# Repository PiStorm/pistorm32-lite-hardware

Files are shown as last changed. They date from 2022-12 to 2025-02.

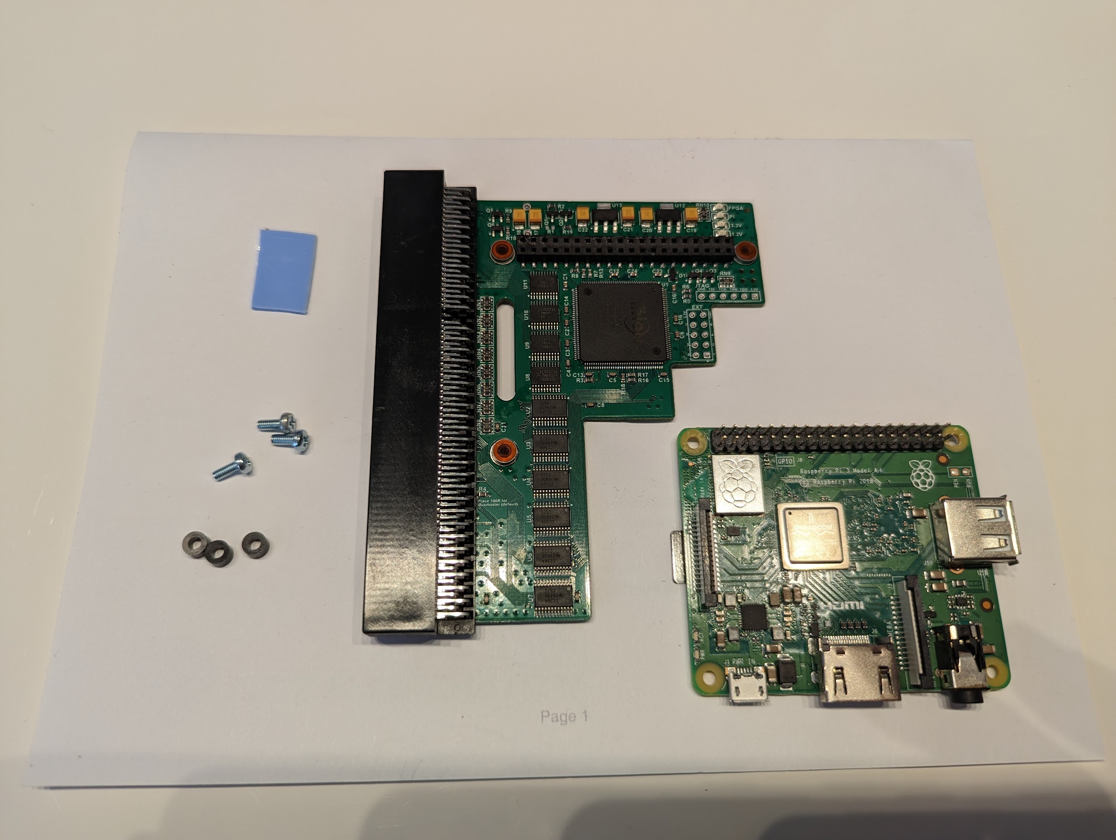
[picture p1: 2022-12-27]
Pictures/parts.jpg

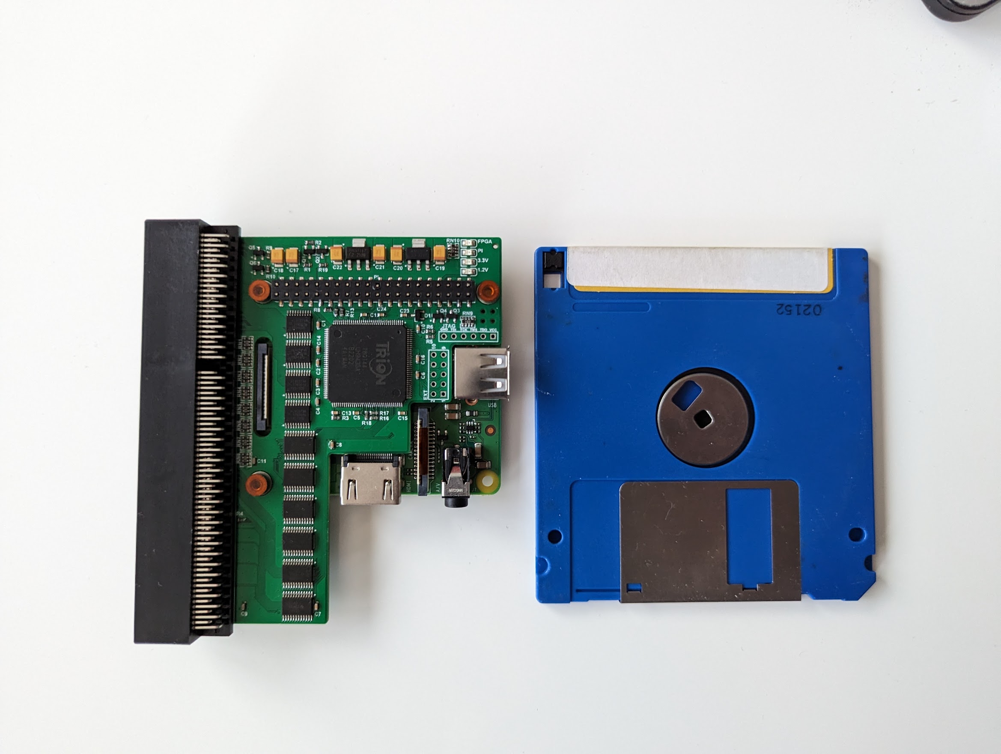
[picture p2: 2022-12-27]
Pictures/PS32_lite_pi3A.jpg

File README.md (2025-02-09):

# PiStorm32-lite
## An Opensource, Raspberry Pi based, Amiga A1200 Accelerator

This repository holds all hardware design and fabrication files

---

PiStorm32-lite is compatible with 
- PI3A
- PI3B
- PI4B
- PiZero2 (could be very tight around the HDMI connector...)

- Raspberry CM4 (Recommended Version : CM4 Lite, 2GB RAM with WIFI and no eMMC) trough a adapter
  https://github.com/PiStorm/cm4board
  
The custom designed CM4 Adapter will offer the best cooling and electrical properties in the constrained space available.



## Direct links
- [Schematics (and assembly drawing)](PDF/ps32_lite_rev_a_public_schematic.pdf)
- [Altium project](Altium/)
- [Fabrication files](Fabrication%20Files/)
- [Fabrication files for JLCPCB Assembly (With small ordering Howto)](JLCPCB/)

---

The community around the PiStorm Project is best reached on Discord



---
> IMPORTANT NOTE: `Isolate the PI GPIO and Ethernet Pins from the A1200 Keyboard, that can be done by 2  or 3 layers of tape attached to the keyboard backside where the Pi pins would touch the metal`
If you don't do that, you likely fry your Pi ! Sorry couldn't design it an other way, there is not much space in the A1200 trapdoor bay 
---

Beside the PCB you also need following parts:

| Designator  | Part | Quantity | Notes
| --- | --- | ----- | ----- |
| C1 to C16, C23, C24 | 100nF 0603 | 18 | X7R 
| C17, C18, C19, C20, C21, C22 | Tantalum 10uF 16V Size B| 6 | --
| D1 | BAT54C | 1 | --
| EXT | 2.54mm Pin Header 2x5 10 Pins | 1 | Expansion header for the future :) e.g.  B-2100S10P-B110
| M1,M2,M3 | SMD M2.5 NUT | 3 | e.g. Sinhoo SMTSO2515CTJ
| LED_1.2, LED_3.3, LED_FPGA, LED_PI | RED LED 0805 | 4 | Indicate not Illuminate!
| PI | SMD 40Pin 2x20 - bottom entry | 1 | e.g. Liansheng FH-00369 
| CN1 | A1200 Edge connector | 1 | see links and notes
| Q1 | IRML6401 | 1 | --
| Q2, Q3, Q4, Q5, Q6 | BC847B | 5 | --
| R2, R4, R5, R6, R7, R8, R9, R10, R19 | Resistor 0603 10kOhm | 9 | --
| R3, R13, R16, R17, R18 | Resistor 0603 1kOhm | 5 | --
| RN1, RN2, RN3, RN4, RN5, RN6, RN7, RN8, RN9| Resistor Array 0603x4 10kOhm | 9 | e.g. YAGEO YC164-JR
| RN10 | Resistor Array 0603x4 1kOhm | 1 | e.g. YAGEO YC164-JR
| U1 | FPGA Efinix Trion T8Q144C4 (or C3) | 1 | see links and notes
| U2, U3, U4, U5, U6, U7 | 74CBTD3384 TSSOP-24 | 6 | TI or NXP
| U8, U9, U10, U11 | 74LVC573A TSSOP-20 | 4 | TI or NXP
| U12 | AMS1117-3.3 3.3V LDO | 1 | --
| U13 | AMS1117-3 1.2 1.2V LDO | 1 | --

> Note: A1200 Edge Connectors can be purchased at [retroready.one](https://retroready.one/products/amiga-1200-genuine-expansion-card-edge-connector-brand-new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)(UK based, highly recommended) or [amigastore.eu](https://amigastore.eu/en/738-amiga-1200-accelerator-connector-for-the-edge-expansion-port.html)(EU based) or [Sordan](https://sordan.ie/product/670/150-pin-90-degrees-amiga-1200-edge-expansion-card-connector/)(Ireland/EU based)

> Note: JLCPCB does not stock the Efinix FPGA, but can source that part trough their [global parts sourcing service](https://jlcpcb.com/help/article/60-How-to-use-JLCPCB-Global-Sourcing-Parts-Service). If you want to assemble the PCB by yourself, or order a partially assembeld PCB without the FPGA then here is a link to Digikey [Digikey FPGA](https://www.digikey.com/short/zh3ph422)

For mechanical assembly you need :

- 3 M2.5 Screws with 8mm thread length (M2.5x8)
- 3 Spacers ID=2.6mm Length=3.0mm 
- 1 Thermal Pad with 1mm thickness, just needs to be big enough to cover the PI CPU 

There are also some [pictures here](Pictures/) how to attach the thermal pad and screws

---

If you like this project and want to support me (Claude Schwarz, PiStorm Hardware) with a donation, I finally setup a donate button :)

The donations will go into further development of open source PiStorm hardware.



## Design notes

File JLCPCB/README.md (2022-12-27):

# PiStorm32-lite
## How to place the order at JLCPCB

- Logic or create a account at [JLCPCB](https://jlcpcb.com/)
- Click on `Instant Quote`
- Upload the ZIP File with the Gerbers

----

First the PCB, if you only want a unpopulated PCB you can of course skip the Assembly part :)

----

## PCB

Check if the Gerber upload looks good


Check the PCB specs (you can also pick a different color or PCB finish of course)


Check that "Remove Order Number" is set like this


----

## Assembly

Select "Top Side" for Assembly and set the tooling holes to "Added by Customer"


Continue to the next Page to upload the BOM (Bill of Material) and CPL (Pick and Place Machine coordinates) files.
You also need to specify the intended use for the assembled PCB, thats for Tax/Customs reasons only. I usually pick
the Research/DIY/Hobby category.



On the next Page you can check the BOM upload and matching to JLCPCB part numbers and stock levels.
For all parts you can also select alternatives from JLCPCBs stock (Loupe symbol), or like in the case of the EFINIX FPGA which
isn't yet on the JLCPCBs stock list, select a part you ordred before at the JLCPCB Global Parts Sourcing Service.
Keep in mind that the Parts you ordered that way must first arrive at the JLCPCB warehouse before the assembly and data prepareation can start.
This takes usually around a week, and you get a email notification when the parts arrived.



When all looks good and the parts, or alternative parts you selected, are on stock proceed to the last page.
Here you can check the placement of the parts prior soldering. JLCPCB corrects small errors like rotated parts, but 
they cant correct errors where, for example, a part is selected with the wrong footprint. So check the picture closely and
if in doubt better double check :) The rendering is not perfect, like the FPGA is missing completly in the rendering.
But when you are sure the part is on stock and you selected it in the BOM page then just trust in JLCPCB. They contact you
also if there is a problem they cant fix by themself for you.



Thats it! Now lean back and wait some days for your assembled PiStorm32-lite boards to arrive

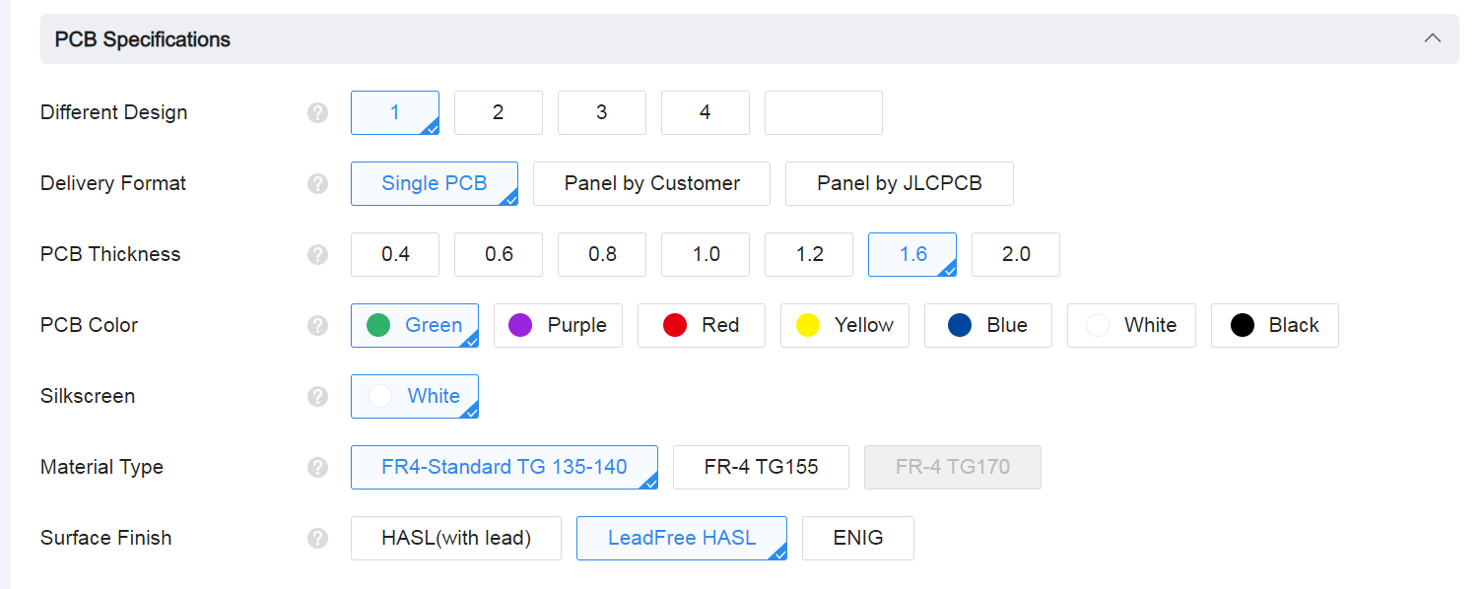
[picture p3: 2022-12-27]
JLCPCB/pictures/pcb_spec.png

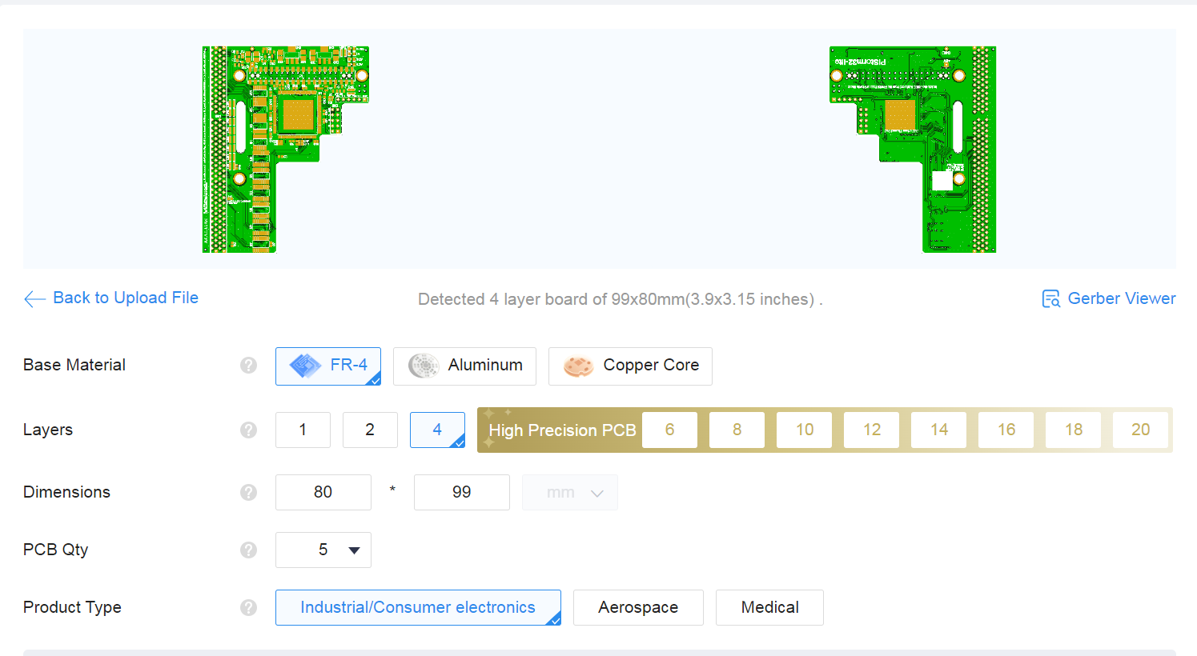
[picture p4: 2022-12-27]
JLCPCB/pictures/gerber upload.png

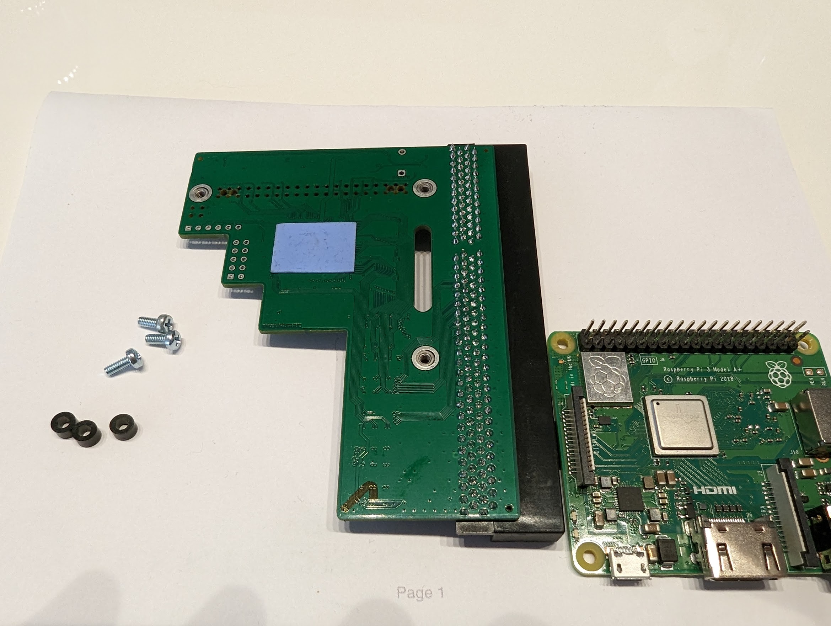
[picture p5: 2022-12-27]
Pictures/thermal_pad.jpg

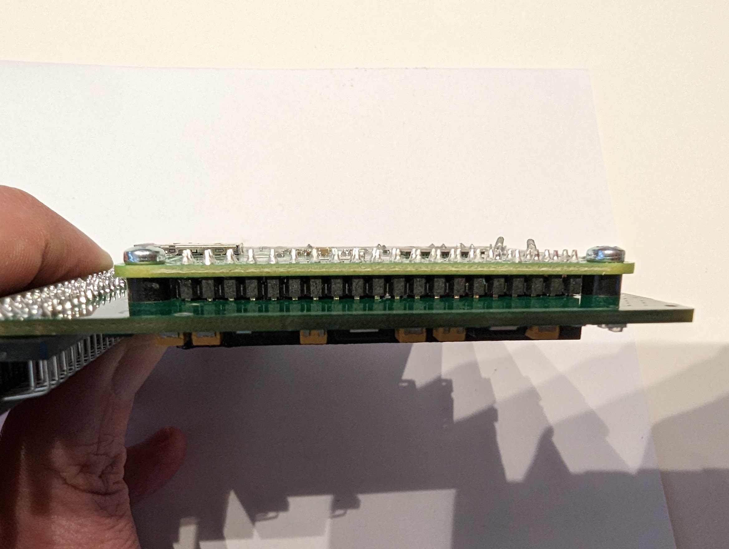
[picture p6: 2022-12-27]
Pictures/spacer.jpg

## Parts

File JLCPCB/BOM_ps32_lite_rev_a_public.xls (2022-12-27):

Comment | Designator | Footprint | JLCPCB Part #
2.2k | RN10 | 2.2k | C136829
10kΩ | RN1,RN2,RN3,RN4,RN5,RN6,RN7,RN8,RN9 | 10kΩ | C29718
TAJA | C17,C18,C19,C20,C21,C22 | TAJA | C7193
IRLML6401 | Q1 | IRLML6401 | C518776
BC847B | Q2,Q3,Q4,Q5,Q6 | BC847B | C181140
T8Q144Cx | U1 | T8Q144Cx | C5246494
BAT54C | D1 | BAT54C | C909965
AMS1117-1.2 | U13 | AMS1117-1.2 | C347218
SN74LVC573APWLE | U8,U9,U10,U11 | SN74LVC573APWLE | C6096
SN74CBTD3384PWLE | U2,U3,U4,U5,U6,U7 | SN74CBTD3384PWLE | C7155
Comment | DESIGNATOR1,DESIGNATOR2,DESIGNATOR3 | Comment | C2915629
FC-2012HRK-620D | LED_1.2,LED_3.3,LED_FPGA,LED_PI | FC-2012HRK-620D | C84256
AMS1117-3.3 | U12 | AMS1117-3.3 | C6186
E0424-846-00 | R2,R4,R5,R6,R7,R8,R9,R10,R19 | E0424-846-00 | C25804
CapSemi | C1,C2,C3,C4,C5,C6,C7,C8,C9,C10,C11,C12,C13,C14,C15,C16,C24,C23 | CapSemi | C14663
1K | R3,R13,R16,R17,R18 | 1K | C21190
Header20X2 | PI | Header20X2 | C2685115

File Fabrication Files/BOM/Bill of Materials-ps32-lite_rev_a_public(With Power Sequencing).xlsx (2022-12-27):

Comment | Designator | Quantity | BOM_Supplier Part
Cap Semi | C1, C2, C3, C4, C5, C6, C7, C8, C9, C10, C11, C12, C13, C14, C15, C16, C23, C24 | 18
TAJA | C17, C18, C19, C20, C21, C22 | 6
A1200-EXPANSION_SLOT | CN1 | 1
BAT54C | D1 | 1
Header 5X2 | EXT | 1
FC-2012HRK-620D | LED_1.2, LED_3.3, LED_FPGA, LED_PI | 4 | C84256
Mount | M1, M2, M3 | 3
Header 20X2 | PI | 1
IRLML6401 | Q1 | 1
BC847B | Q2, Q3, Q4, Q5, Q6 | 5
E0424-846-00 | R2, R4, R5, R6, R7, R8, R9, R10, R19 | 9
E0424-846-00 | R3, R13 | 2
1K | R16, R17, R18 | 3
10kΩ | RN1, RN2, RN3, RN4, RN5, RN6, RN7, RN8, RN9 | 9 | C29718
2.2k | RN10 | 1 | C29718
T8Q144Cx | U1 | 1
SN74CBTD3384PWLE | U2, U3, U4, U5, U6, U7 | 6
SN74LVC573APWLE | U8, U9, U10, U11 | 4
AMS1117-3.3 | U12 | 1
AMS1117-1.2 | U13 | 1

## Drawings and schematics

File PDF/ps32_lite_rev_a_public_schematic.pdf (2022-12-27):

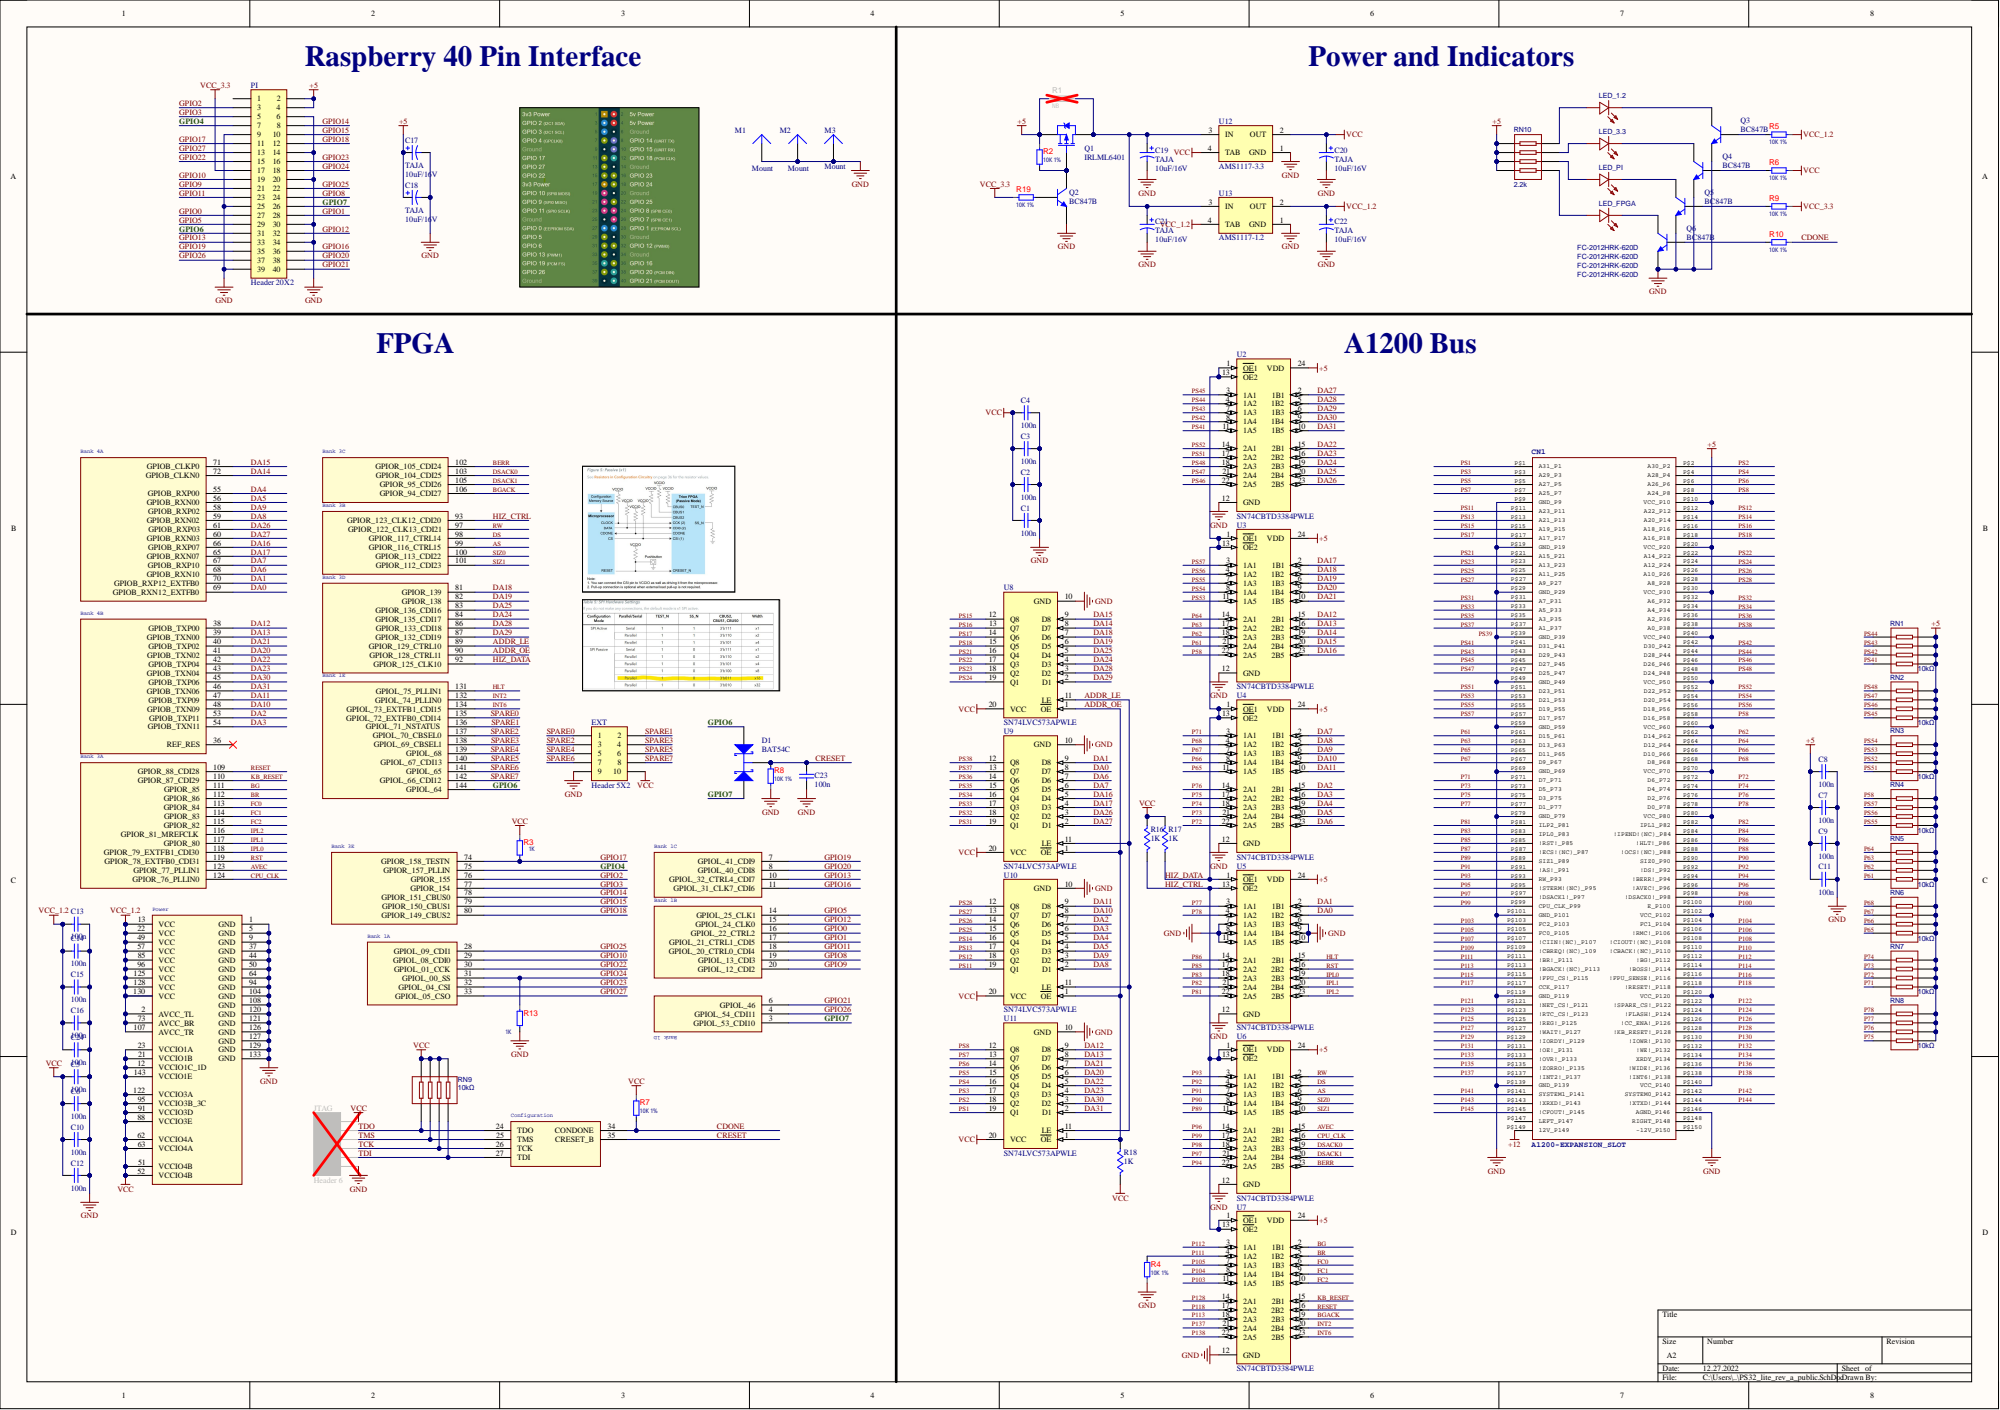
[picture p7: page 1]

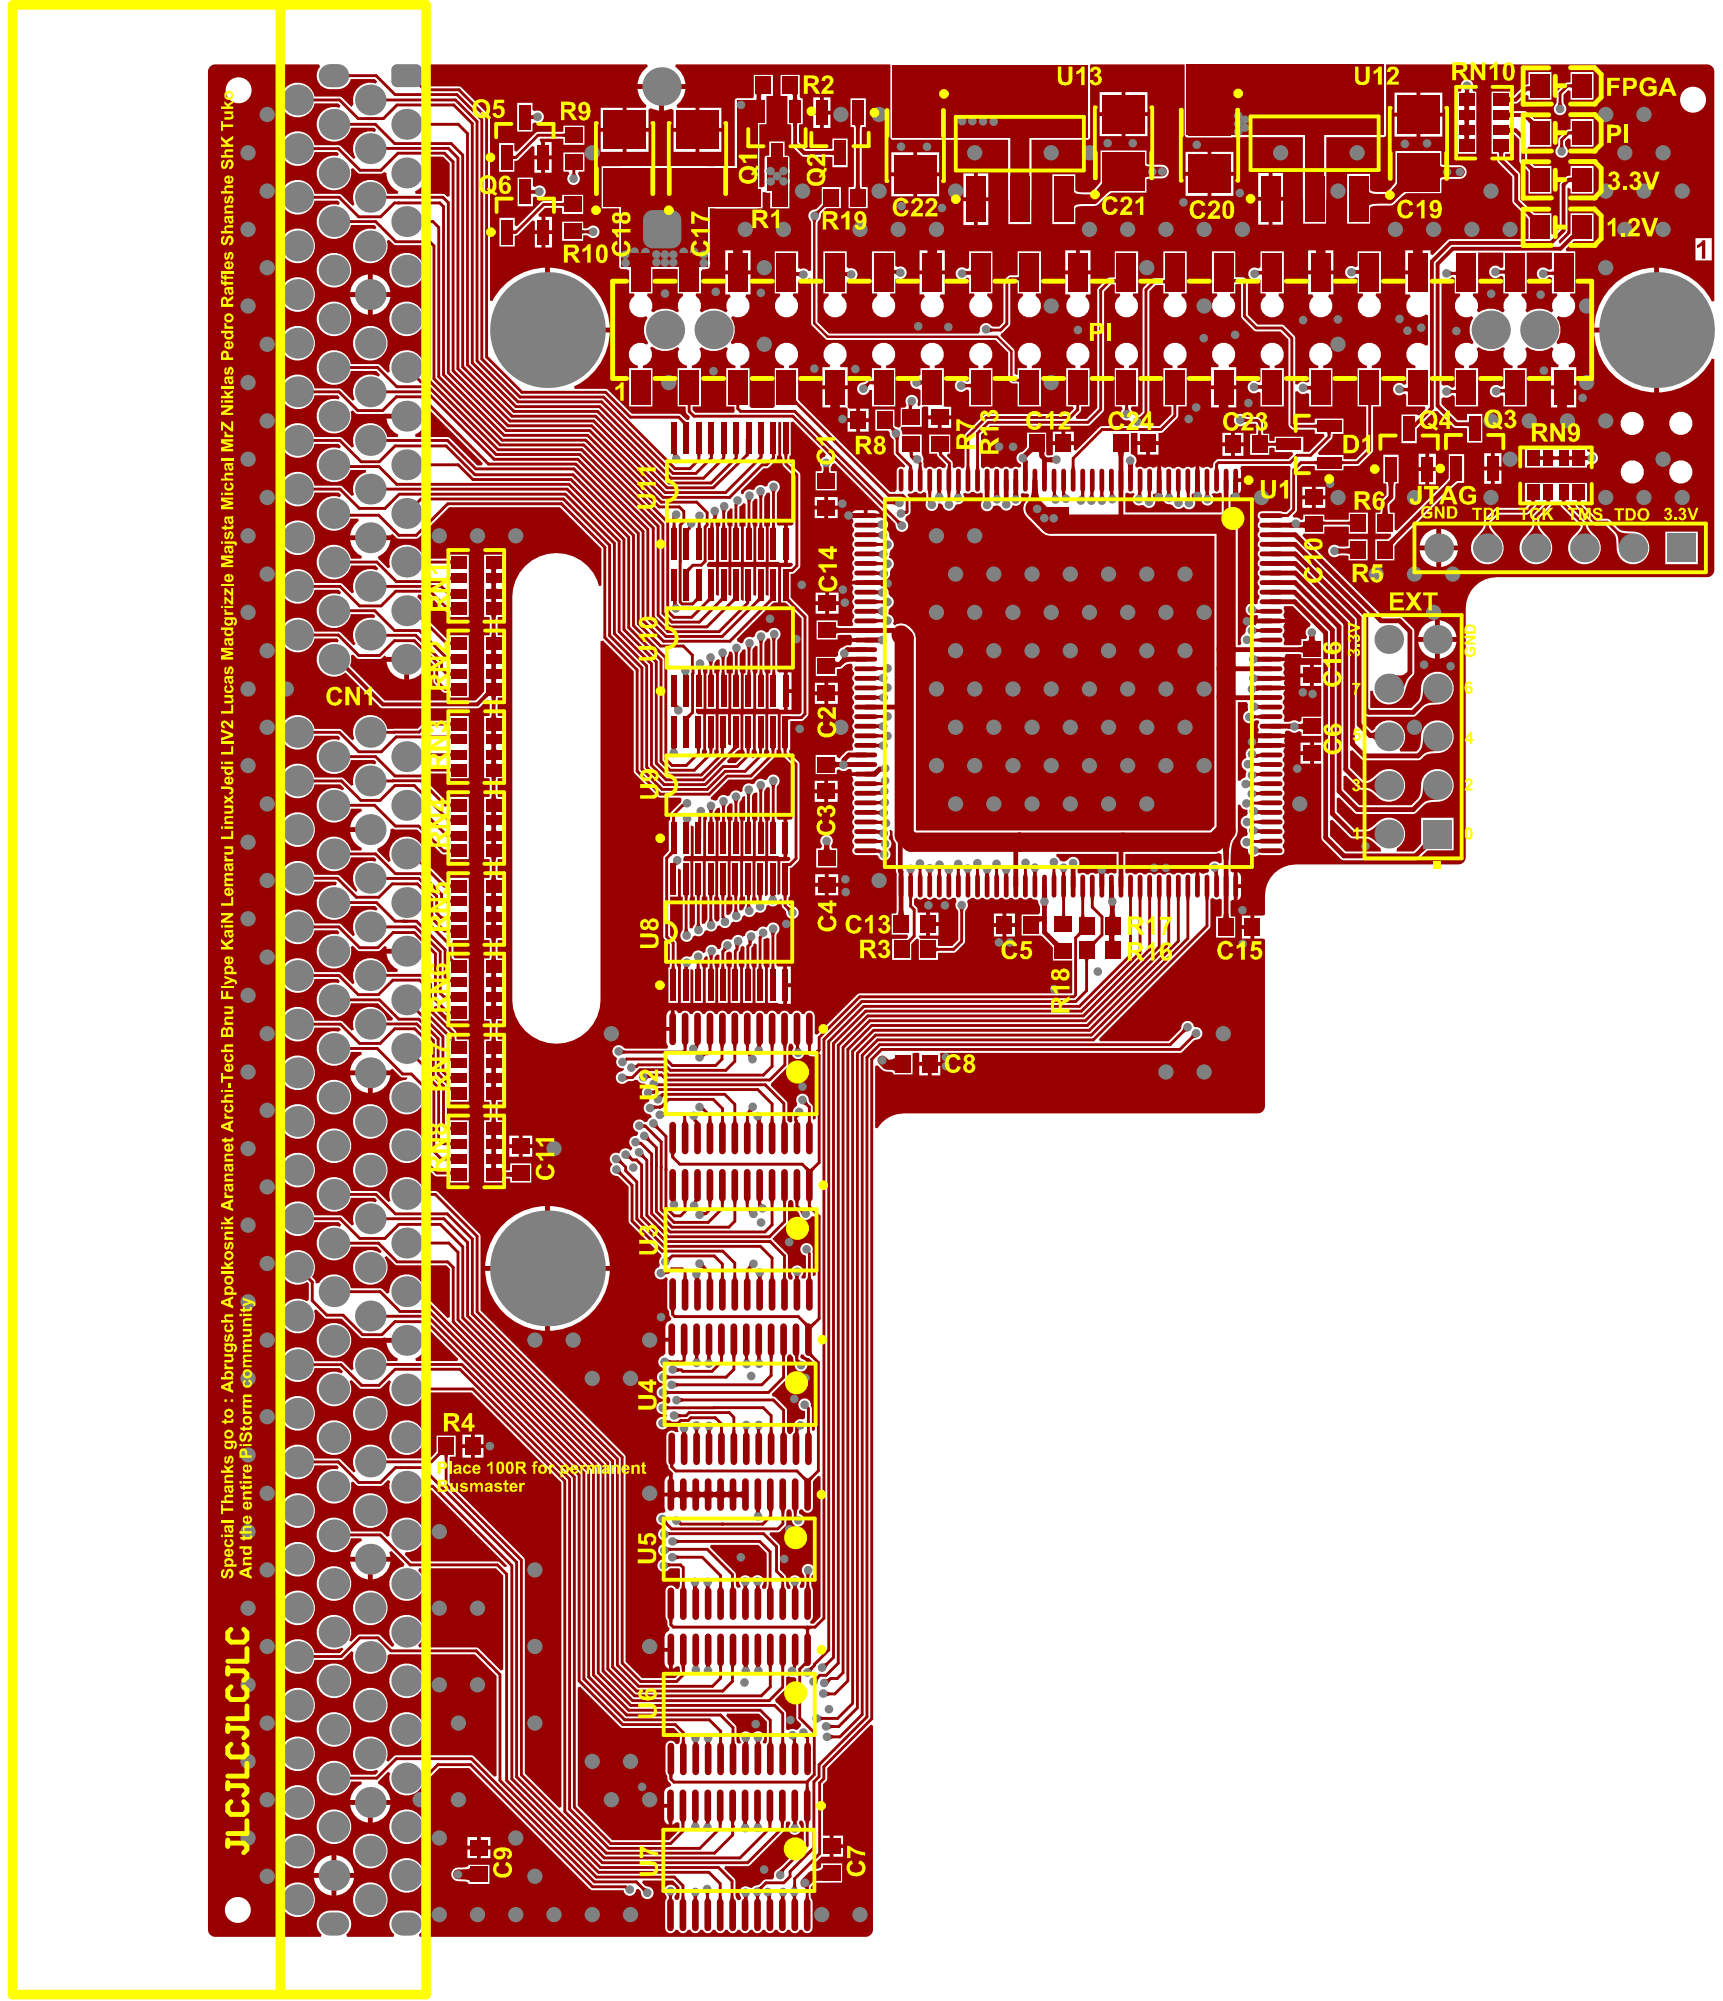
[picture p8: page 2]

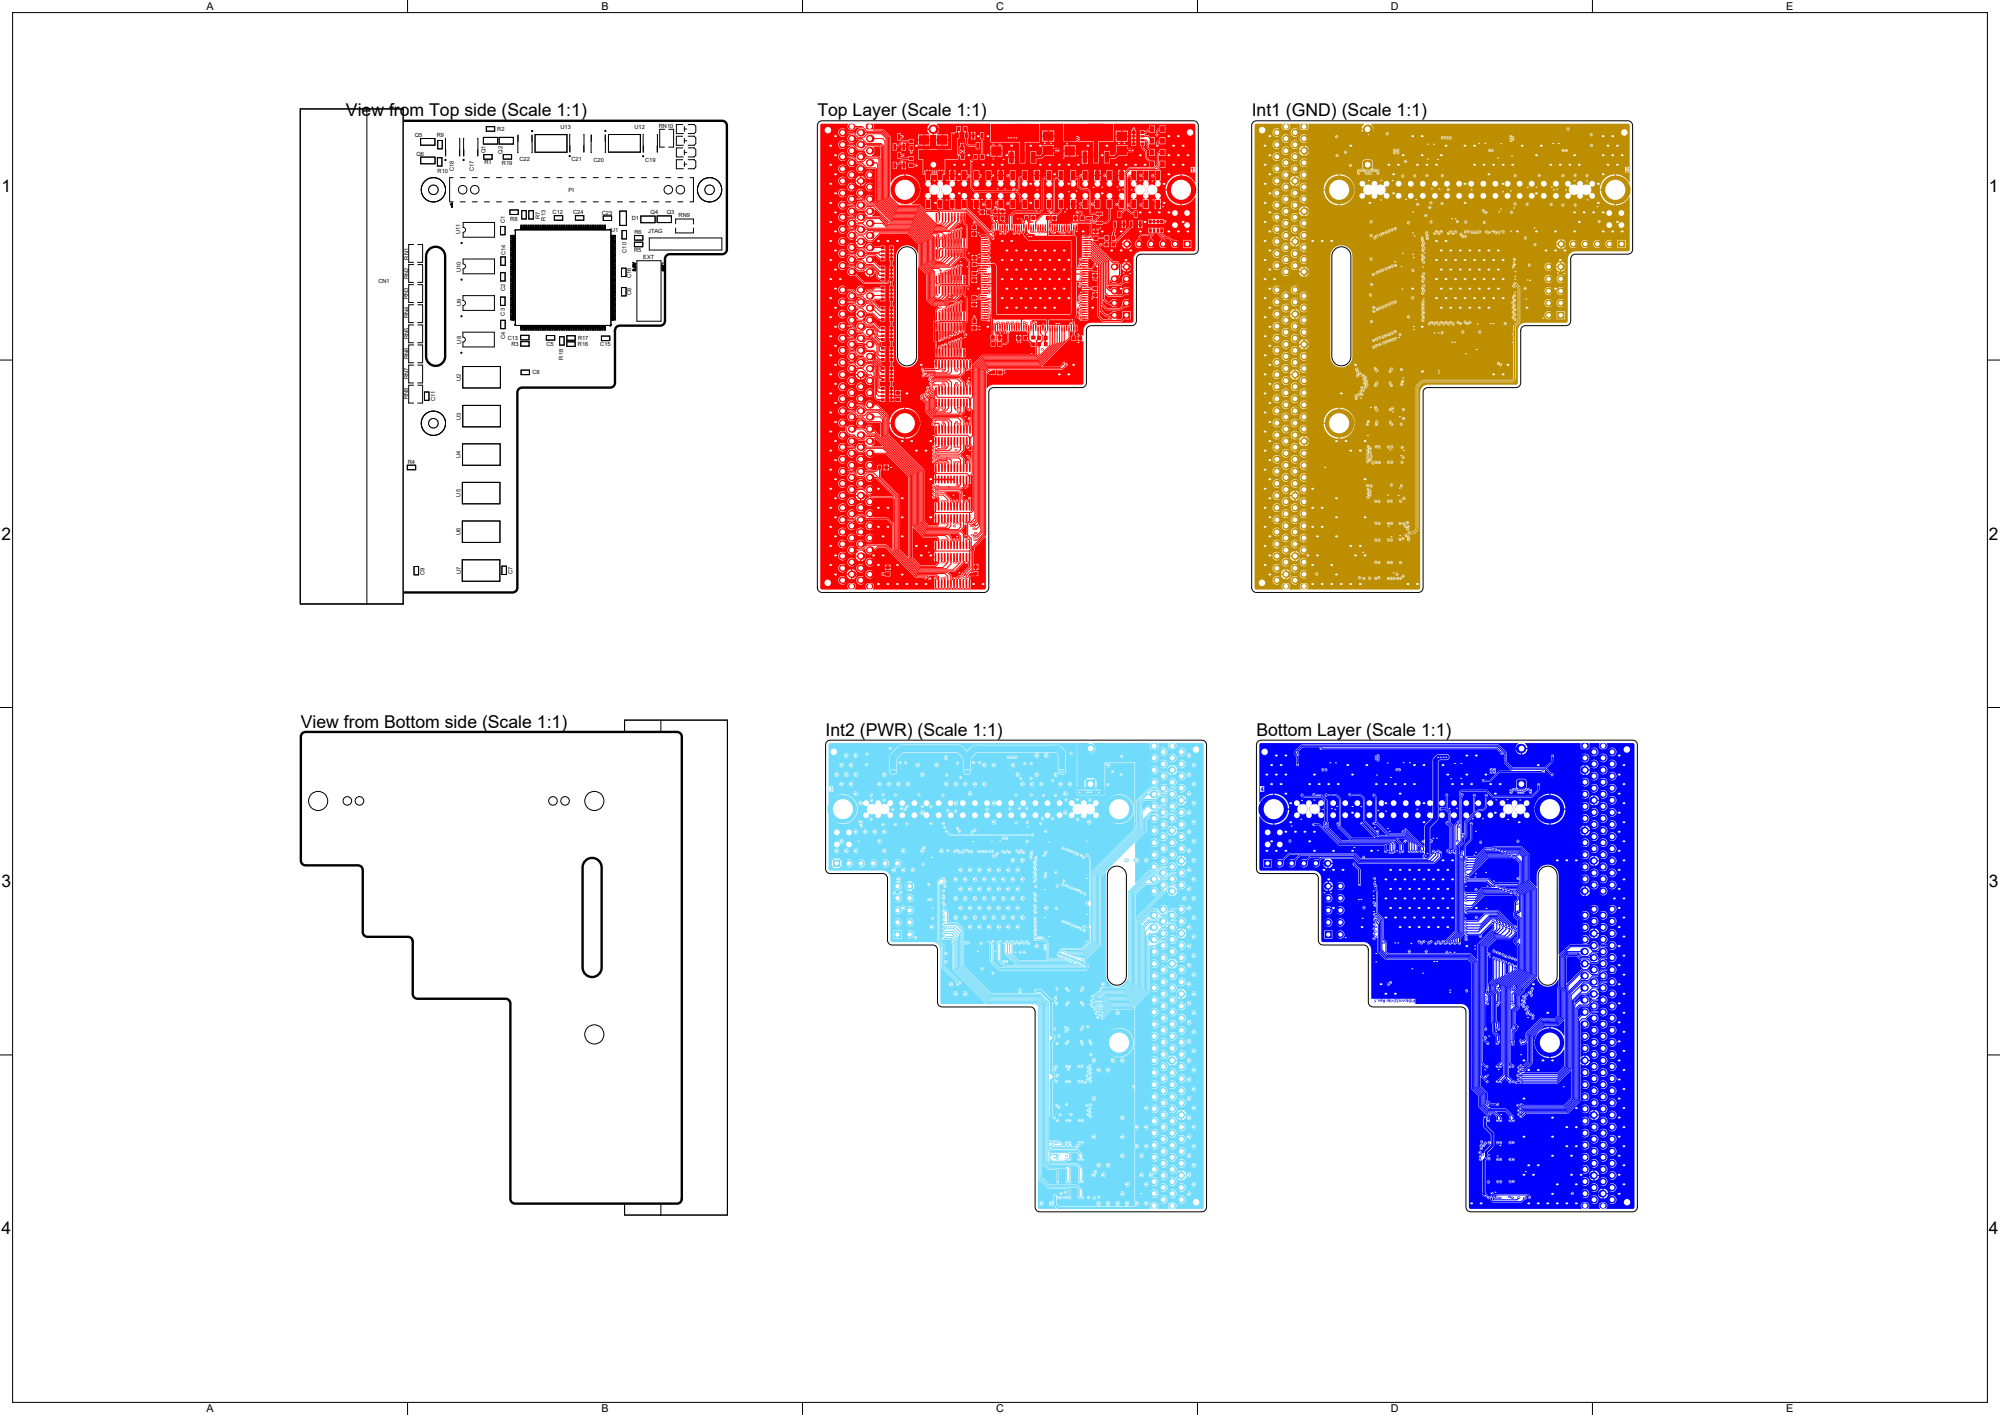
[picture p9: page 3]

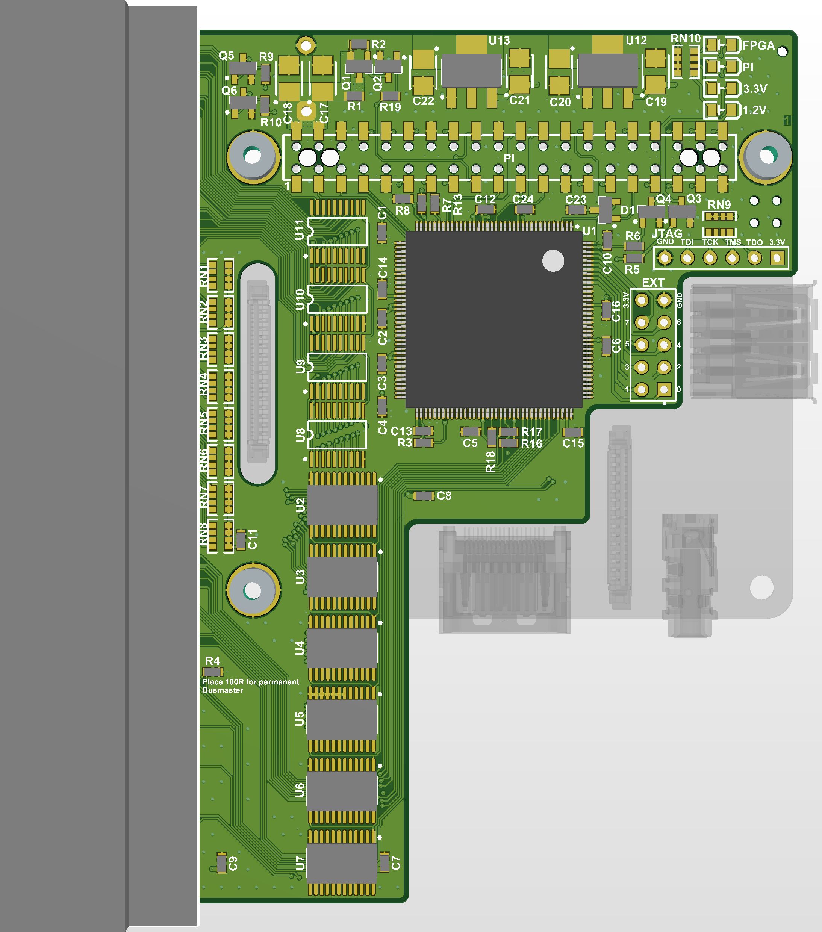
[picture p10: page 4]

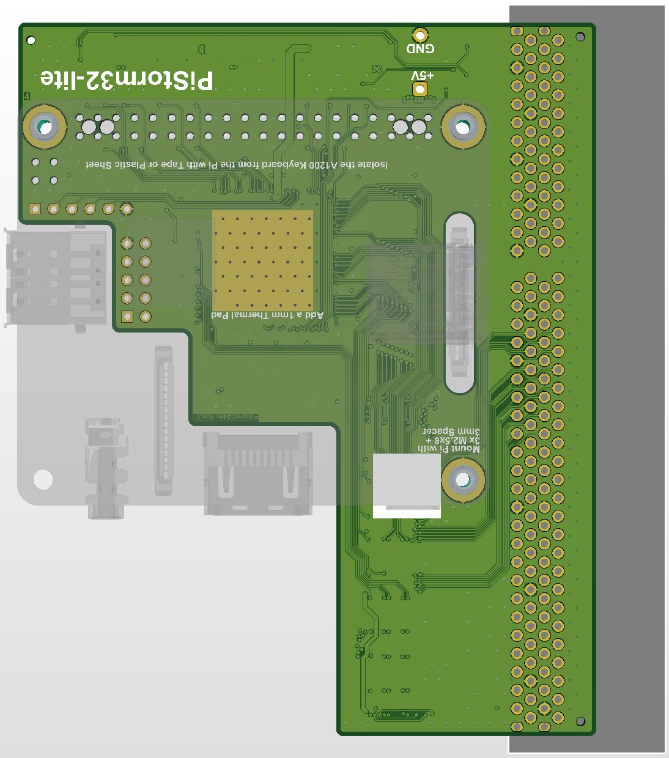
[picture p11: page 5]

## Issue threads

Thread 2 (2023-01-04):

Q1  180 degree misaligned  in pick and place file

kipper2k, 2023-01-04:
Great board :) , noticed an error in CPL file. Q1 needs to be rotated 180 degrees

captain-amygdala, 2023-01-05:
Thanks for reporting. Will fix that.
JLCPCB corrects this automatically, but still good to have the PnP files correct.

Closed 2023-01-05.

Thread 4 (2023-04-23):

Slow AGA playback performance

Pixelsmack, 2023-04-23:
I am seeing very slow AGA animation playback ob Amiga A1200. When compared to same Amiga with 68060 accelerator. Considering how fast the PiStorm32 is, this seems weird. I know others ave shown certain AGA games and even non AGA games running slow. This maybe similar issue?

Here are links to the two test files I was using. They are extreme examples but the idea was to push the hardware. Either real 68060 or devices like PiStorms.

HAM6 ANIM: https://drive.google.com/file/d/1RP-bD8ktdwqTNmUBqyE6z1aS05qCAhJ9/view?usp=share_link

HAM8 ANIM: https://drive.google.com/file/d/1RWZ4pzAwK7EIeeuaI8MJYQgJKRSbSyna/view?usp=share_link

macphreak4evr, 2023-04-23:
most aga games shadow or have strange artifact issues. . i have done a video showing these too coming out in a few days

Pixelsmack, 2023-04-23:
Here are the two software programs I used in WB3.2.2 to play/test these files

clarissa: https://drive.google.com/file/d/1F2OvnzePMJfmSAosi1TYwCJwA70tMvSd/view?usp=share_link

MainActor: https://drive.google.com/file/d/1nvv3M9ytHEvx3anFXnwNprRXUhYjS07i/view?usp=share_link

Unpack both to your drive and run.

michalsc, 2023-04-23:
Thanks for reporting. Once I will manage to find out whether it is Emu68 or PiStorm32 related I will move it to corresponding project.

danielktdoranie, 2023-04-24:
I just want to confirm I had the same experience with these files running a PiStorm32 with Raspberry Pi Model B 3+ and CaffeineOS version 919

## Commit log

2022-12-27 Inital uploads
    [BOM_ps32_lite_rev_a_public.xls, Bill of Materials-ps32-lite_rev_a_public(With Power Sequencing).xlsx, PS32-lite-rev_a_public.PrjPcb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]
2022-12-29 Updated BOM in README.md, Part# EXT Header
2023-01-05 CPL File - Correction of Q1 rotation
    [CPL_ps32_lite_rev_a_public.csv]
2023-01-09 Warning about the soldering issue
